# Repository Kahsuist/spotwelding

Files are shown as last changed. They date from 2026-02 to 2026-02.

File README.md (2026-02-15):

# Максимально бюджетный аппарат точечной сварки для 18650 и подобных





Полевые ключи от матринской платы по питанию процессора. OLED-дисплей 0.96". Bluepill на STM32 c алиэкспресс. 

**Архивный проект 2023 года** — аппарат точечной сварки двухимпульсный (разогрев + сварка) на базе STM32. Используется в комплекте с автомобильным аккумулятором, но подойдет любой высокотоковый 12в. Можно использовать конденсаторное питание, но я не тестировал, так как ставилась цель сотни непрерывных сварок подряд.

https://github.com/user-attachments/assets/1fbc5b3e-b446-4555-8be0-63c3d0c397dd

## Возможности

- Приваривает ленту с алиэкспресс 0.12*7мм к Li-ion аккумуляторам (18650 и др.)
- Автоматическая ручка с регулировкой прижима - гарантирует стабильное усилие на обоих электродах в момент сварки.
- Ручка автоматически подает сварочные импульсы в момент оптимального прижатия ОБОИХ электродов.
- Качество сварки без почернений, прожигов, непроваров (!!! необходимо настроить под свою ленту, так как часто не известно что у вас в руках!)
- OLED-дисплей отображает длительность двух импульсов и длительность паузы между ними и напряжение на аккумуляторе.
- Клавиатура позволяет настроить все три длительности.
- Возможности сохранить предустановки нет, при подключении к питанию берутся дефолтные значения из кода.
- Работает на STM32F103 (Blue Pill / Black Pill и т.п.)
- ВНИМАНИЕ!!! настройка длительностей более 10-15 миллисекунд приводит к выгоранию полевых ключей !!!

## Фото устройства

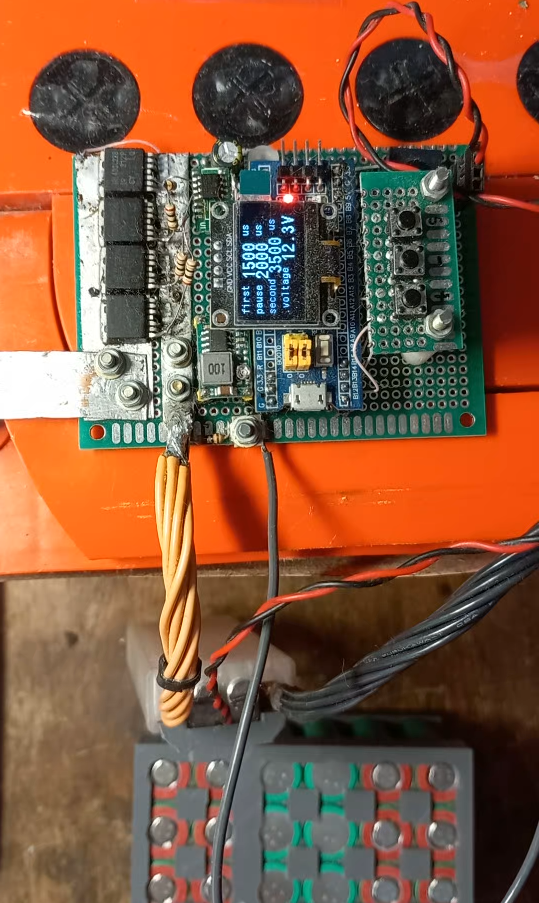
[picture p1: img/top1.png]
Собранное устройство сверху
  
*Собранное устройство (вид сверху)*

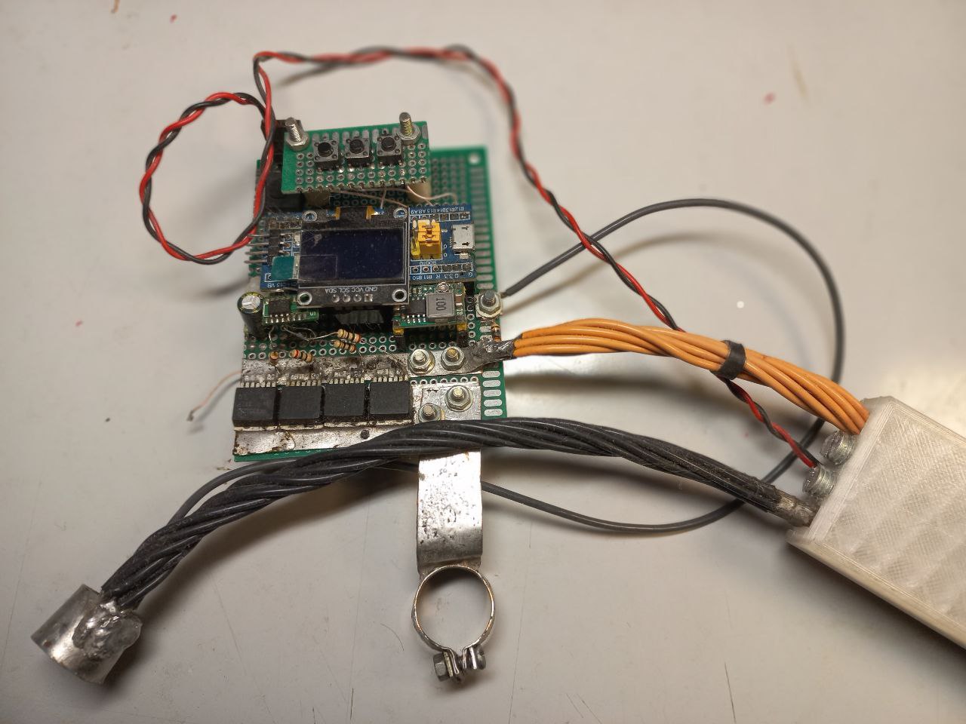
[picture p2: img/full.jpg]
Собранное устройство общий
  
*Собранное устройство (общий вид)*

## Фото автоматической сварочной ручки

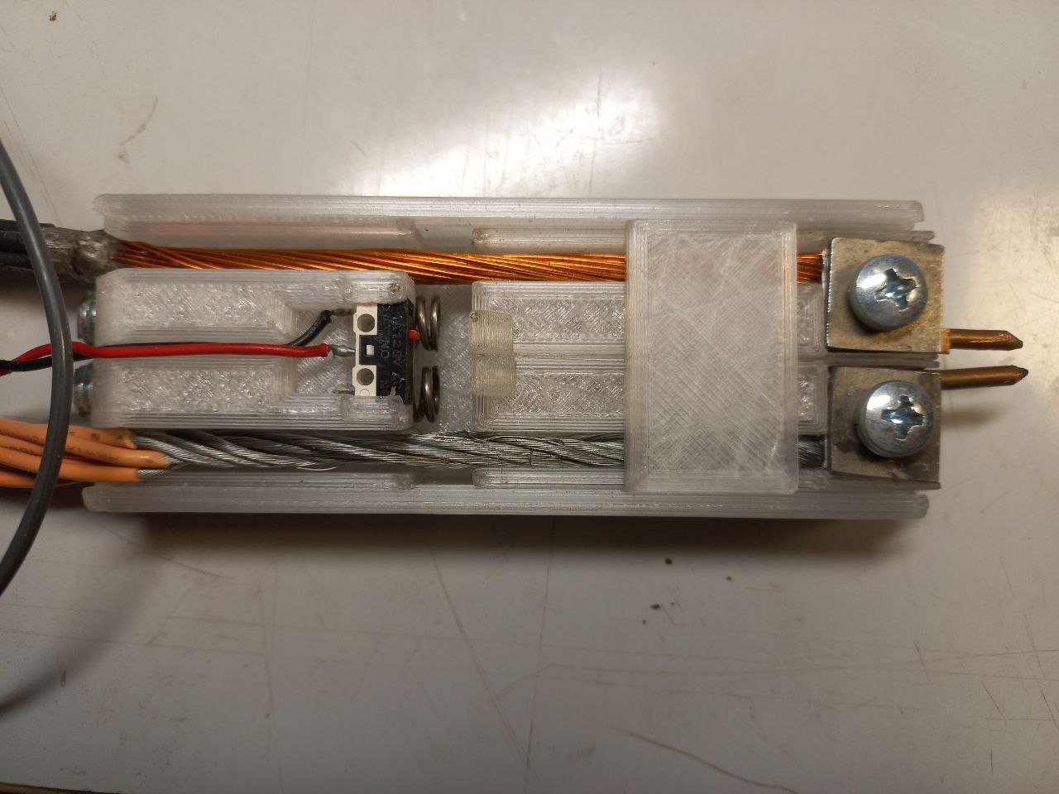
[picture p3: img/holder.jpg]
Сварочная ручка
  
*Сварочная ручка*

## Электрическая схема

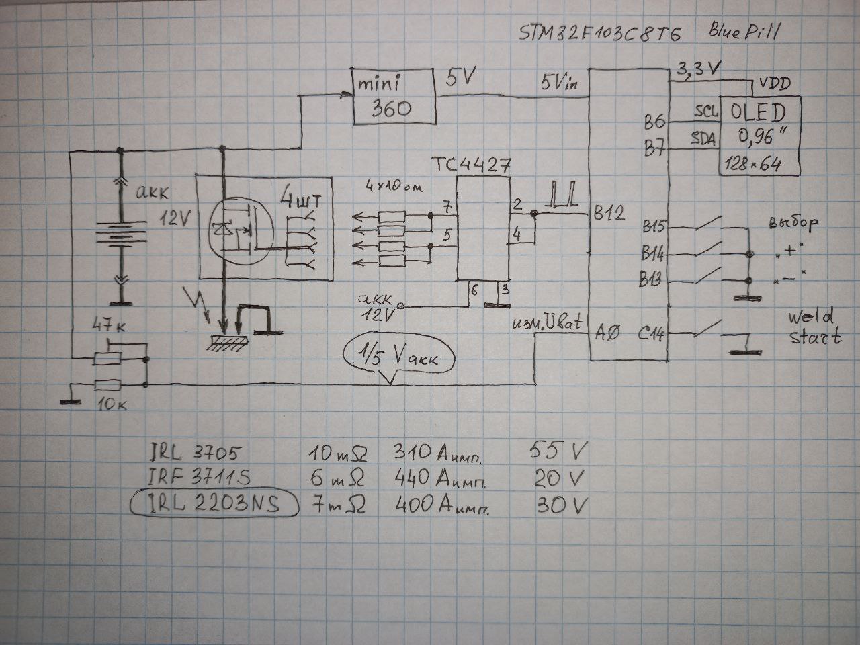
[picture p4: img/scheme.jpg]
Схема на бумаге
  
*Полная электрическая схема*

Подробные файлы схемы:  
- (в планах) ~~[KiCad проект → schematic.kicad_sch](hardware/schematics/)~~
- (в планах) ~~[Экспорт в PDF → schematic.pdf](hardware/schematics/schematic.pdf)~~

## Как открыть и собрать проект

1. Установи **STM32CubeIDE** (изначально создавался в 1.4, позже компилировался в версии 1.7)
2. File → Open Projects from File System... → укажи корень репозитория
3. Открой файл `*.ioc` в STM32CubeMX (если нужно изменить пины/настройки)
4. Project → Build All
5. Подключи ST-Link / USB → Run / Debug

**Прошивка без IDE** (опционально):  
Используй `*.hex` / `*.bin` из папки Release/Debug + STM32CubeProgrammer или dfu-util. (в репо не залиты, это сообщение оставлено для памяти)

## Как использовать

1. Подключи устройство к аккумулятору
2. При первых пробах подбери длительности по качеству сварки: провар должен быть 100% надежный, без прогаров, без почернений. !!! НЕ УВЛЕКАЙСЯ большими длительностями (max 10 миллисекунд) !!! 
3. ВАЖНО! - Перед использованием ленту необходимо подготовить - сделать продольные прорезы между точками сварки, на концах ножницами, в серединках - дримером (бормашинкой) с алмазным диском. БЕЗ прорезов качество становится неконтролируемым и требуются токи, не совместимые с дешевыми полевыми ключами !!! (я вообще использовал ключи, снятые с мертвых материнских плат по питанию процессора)
4. ВАЖНО обсепечить чистые поверхности, без мусора, между лентой и аккумулятором для обеспечения надежного контакта для прохождения сварочного тока.

## Зависимости / Требования

- STM32CubeIDE / STM32CubeMX
- STM32F103C8/R8 серия bluepill

## Disclaimer

Проект старый, не поддерживается.  
Это рабочий отлаженный прототип. Но возможен апгрейд проекта (например добавить запоминание настроек, настройка с телефона по блютуз, сбор статистики и др.) при обоюдовыгодном интересе.

Используй на свой страх и риск.  
Сообщения об ошибках / PR приветствуются!

## Лицензия

MIT License — см. файл [LICENSE](LICENSE)

## Контакты

Если хотите со мной связаться: телега @kahsuist

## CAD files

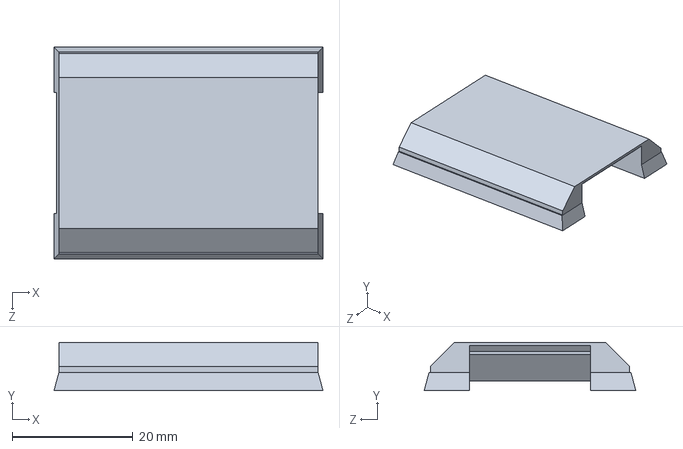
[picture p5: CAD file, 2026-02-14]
3Dmodels/крышка.SLDPRT
44.6 x 8.00 x 35.1 mm

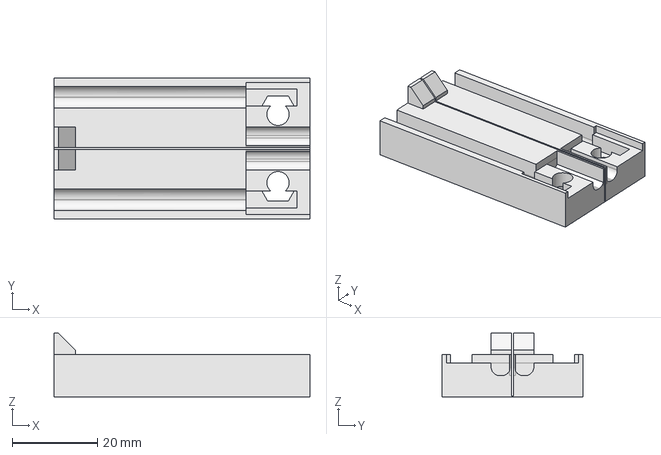
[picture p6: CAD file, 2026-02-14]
3Dmodels/base.FCStd
60.0 x 33.0 x 15.0 mm

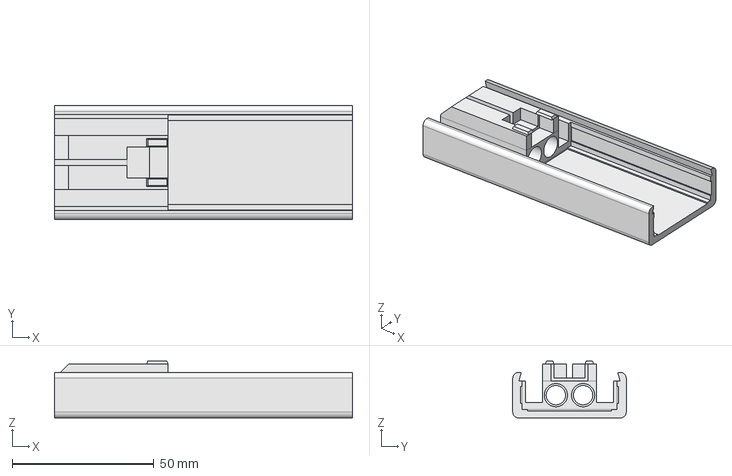
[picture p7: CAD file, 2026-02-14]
3Dmodels/shassi.FCStd
105.0 x 40.0 x 20.0 mm

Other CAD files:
3Dmodels/base.stl
3Dmodels/shassi.stl
3Dmodels/крышка.STL

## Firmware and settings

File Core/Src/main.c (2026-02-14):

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
/* Includes ------------------------------------------------------------------*/
#include "main.h"

/* USER CODE BEGIN Includes */
#include "ssd1306.h"
#include "fonts.h"
/* USER CODE END Includes */

/* USER CODE BEGIN PD */
#define DWT_CONTROL *(volatile unsigned long *)0xE0001000
#define SCB_DEMCR   *(volatile unsigned long *)0xE000EDFC
/* USER CODE END PD */

ADC_HandleTypeDef hadc1;

I2C_HandleTypeDef hi2c1;

TIM_HandleTypeDef htim2;

/* USER CODE BEGIN PV */
// кнопки
int8_t Select = 0;
int8_t position = 4;
int8_t value_up = 0;
int8_t value_down = 0;
int8_t letsWelding = 0;
uint32_t time_key_press = 0;// time_key_press = HAL_GetTick(); (HAL_GetTick() - time_key1_press) > 300
int8_t correction = 14; // поправка, причина в стартовой задержке в 14 микросекунд в delay_microseconds(), я не знаб почему

int voltage = 12;
char str[5];
int firstPulse = 400;
int pause = 3200;
int secondPulse = 1400;
/* USER CODE END PV */

void SystemClock_Config(void);
static void MX_GPIO_Init(void);
static void MX_I2C1_Init(void);
static void MX_ADC1_Init(void);
static void MX_TIM2_Init(void);
/* USER CODE BEGIN 0 */
void usDelay(uint16_t useconds)
{
  __HAL_TIM_SET_COUNTER(&htim2, 0);
  while(__HAL_TIM_GET_COUNTER(&htim2) < useconds);
}

void DWT_Init(void) // OK
{
    SCB_DEMCR |= CoreDebug_DEMCR_TRCENA_Msk; // разрешаем использовать счётчик
	DWT_CONTROL |= DWT_CTRL_CYCCNTENA_Msk;   // запускаем счётчик
}

void blinkLED(int count)
{
	for(int i=0; i<count; i++)
	{
		HAL_GPIO_WritePin(led13_GPIO_Port, led13_Pin, GPIO_PIN_RESET);
		HAL_Delay(100);
		HAL_GPIO_WritePin(led13_GPIO_Port, led13_Pin, GPIO_PIN_SET);
		HAL_Delay(100);
	}
	HAL_Delay(300);
}

void delay_microseconds(uint32_t usec)
{
    uint32_t us_count_tic =  usec * (SystemCoreClock / 1000000);
    DWT->CYCCNT = 0U; // обнуляем счётчик
    while(DWT->CYCCNT < us_count_tic); //{blinkLED(1);}
}

void test_uSecondDelayFunc(void)
{
	int i=0;
	  while(1)
	  {
		HAL_GPIO_TogglePin(WELD_OUT_GPIO_Port, WELD_OUT_Pin);
		//usDelay(40); // 10->100 uSec 40->370 uSec
		delay_microseconds(100); // 1->14uSec 10->24uSec 100->114uSec
		i+=1;
		if(i>100000) break;
	  }
}

void updateDelays(int inc)
{
	if(position==1) firstPulse = firstPulse + inc;
	if(position==2) pause = pause + inc;
	if(position==3) secondPulse = secondPulse + inc;
}

void keyboard(void)
{
	if(Select==0 && HAL_GPIO_ReadPin(GPIOB, BTN_SELECT_Pin)==GPIO_PIN_RESET)
	{
		time_key_press = HAL_GetTick();
		Select=1;
		if(position==4) position=1;
		else position++;
	}
	if(Select>0 && (HAL_GetTick() - time_key_press) > 300) Select=0;

	if(value_up==0 && HAL_GPIO_ReadPin(GPIOB, BTN_UP_Pin)==GPIO_PIN_RESET)
	{
		time_key_press = HAL_GetTick();
		value_up=1;
		updateDelays(100);
	}
	if(value_up>0 && (HAL_GetTick() - time_key_press) > 300) value_up=0;

	if(value_down==0 && HAL_GPIO_ReadPin(GPIOB, BTN_DOWN_Pin)==GPIO_PIN_RESET)
	{
		time_key_press = HAL_GetTick();
		value_down=1;
		updateDelays(-100);
	}
	if(value_down>0 && (HAL_GetTick() - time_key_press) > 300) value_down=0;

	if(letsWelding==0 && HAL_GPIO_ReadPin(LETS_WELD_GPIO_Port, LETS_WELD_Pin)==GPIO_PIN_RESET)
	{
		time_key_press = HAL_GetTick();
		letsWelding=1;
	}
	if(letsWelding>0 && (HAL_GetTick() - time_key_press) > 300) letsWelding=0;
}


/* USER CODE END 0 */

/**
  * @brief  The application entry point.
  * @retval int
  */
int main(void)
{
  /* MCU Configuration--------------------------------------------------------*/

  /* Reset of all peripherals, Initializes the Flash interface and the Systick. */
  HAL_Init();

  /* Configure the system clock */
  SystemClock_Config();

  /* Initialize all configured peripherals */
  MX_GPIO_Init();
  MX_I2C1_Init();
  MX_ADC1_Init();
  MX_TIM2_Init();
  /* USER CODE BEGIN 2 */
  SSD1306_Init();


  SSD1306_GotoXY(0,0);
  SSD1306_Puts ("Welding", &Font_11x18, 1);
  SSD1306_GotoXY(10,30);
  SSD1306_Puts ("Machine", &Font_11x18, 1);
  SSD1306_UpdateScreen();
  HAL_Delay(1500);
  blinkLED(1);

  //test_uSecondDelayFunc();



  SSD1306_Clear();

  HAL_TIM_Base_Start_IT(&htim2);

  /* USER CODE END 2 */

  /* Infinite loop */
  /* USER CODE BEGIN WHILE */
  while (1)
  {
	  keyboard();

	  HAL_ADC_Start(&hadc1);
	  HAL_ADC_PollForConversion(&hadc1, 100);
	  voltage = HAL_ADC_GetValue(&hadc1); // "T: %d.%d ->%d %d", temperatura/10, temperatura-(temperatura/10)*10,
	  int volH = voltage*0.0041;
	  int volL = (voltage*0.0041-volH)*10;
	  HAL_ADC_Stop(&hadc1);

	  if(Select==1 || value_up==1 || value_down==1) SSD1306_Clear();

	  SSD1306_GotoXY(1,0);
	  if(position==1) SSD1306_Puts (".", &Font_7x10, 1);
	  SSD1306_Puts ("first ", &Font_7x10, 1);
	  sprintf((char *)str, "%d", firstPulse);
      SSD1306_Puts (str, &Font_11x18, 1);
      SSD1306_Puts (" us", &Font_7x10, 1);

      SSD1306_GotoXY(1,15);
      if(position==2) SSD1306_Puts (".", &Font_7x10, 1);
      SSD1306_Puts ("pause ", &Font_7x10, 1);
      sprintf((char *)str, "%d", pause);
      SSD1306_Puts (str, &Font_11x18, 1);
      SSD1306_Puts (" us", &Font_7x10, 1);

      SSD1306_GotoXY(1,30);
      if(position==3) SSD1306_Puts (".", &Font_7x10, 1);
      SSD1306_Puts ("second ", &Font_7x10, 1);
      sprintf((char *)str, "%d", secondPulse);
      SSD1306_Puts (str, &Font_11x18, 1);
      SSD1306_Puts (" us", &Font_7x10, 1);

      SSD1306_GotoXY(1,45);
      if(position==4) SSD1306_Puts (".", &Font_7x10, 1);
      SSD1306_Puts ("voltage ", &Font_7x10, 1);
      sprintf((char *)str, "%d.%d", volH, volL);
      SSD1306_Puts (str, &Font_11x18, 1);
      SSD1306_Puts ("V ", &Font_11x18, 1);

	  SSD1306_UpdateScreen();
	    //HAL_Delay(200);

    /* USER CODE END WHILE */

    /* USER CODE BEGIN 3 */
	if(letsWelding==1)
	{
		blinkLED(1);
		HAL_GPIO_WritePin(WELD_OUT_GPIO_Port, WELD_OUT_Pin, GPIO_PIN_SET);
		blinkLED(2);
	    delay_microseconds(firstPulse-correction); // 	1->14uSec 10->24uSec 100->114uSec
	    blinkLED(3);
	    HAL_GPIO_WritePin(WELD_OUT_GPIO_Port, WELD_OUT_Pin, GPIO_PIN_RESET);
	    delay_microseconds(pause-correction);
	    HAL_GPIO_WritePin(WELD_OUT_GPIO_Port, WELD_OUT_Pin, GPIO_PIN_SET);
	    delay_microseconds(secondPulse-correction);
	    HAL_GPIO_WritePin(WELD_OUT_GPIO_Port, WELD_OUT_Pin, GPIO_PIN_RESET);
	    HAL_Delay(500);
	    letsWelding=0;
	}
	    //HAL_GPIO_WritePin(WELD_OUT_GPIO_Port, WELD_OUT_Pin, GPIO_PIN_SET); // WELD_OUT_GPIO_Port, WELD_OUT_Pin, GPIO_PIN_RESET

	    //HAL_TIM_PeriodElapsedCallback(&htim2);
	  //test_uSecondDelayFunc();
  }
  /* USER CODE END 3 */
}

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
/* USER CODE BEGIN 4 */
void HAL_TIM_PeriodElapsedCallback(TIM_HandleTypeDef *htim)
{
        if(htim->Instance == TIM2) //check if the interrupt comes from TIM1
        {
                //HAL_GPIO_TogglePin(led13_GPIO_Port, led13_Pin);
        }
}
/* USER CODE END 4 */
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


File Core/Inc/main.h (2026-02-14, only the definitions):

#define led13_Pin GPIO_PIN_13
#define led13_GPIO_Port GPIOC
#define LETS_WELD_Pin GPIO_PIN_14
#define LETS_WELD_GPIO_Port GPIOC
#define WELD_OUT_Pin GPIO_PIN_12
#define WELD_OUT_GPIO_Port GPIOB
#define BTN_DOWN_Pin GPIO_PIN_13
#define BTN_DOWN_GPIO_Port GPIOB
#define BTN_UP_Pin GPIO_PIN_14
#define BTN_UP_GPIO_Port GPIOB
#define BTN_SELECT_Pin GPIO_PIN_15
#define BTN_SELECT_GPIO_Port GPIOB

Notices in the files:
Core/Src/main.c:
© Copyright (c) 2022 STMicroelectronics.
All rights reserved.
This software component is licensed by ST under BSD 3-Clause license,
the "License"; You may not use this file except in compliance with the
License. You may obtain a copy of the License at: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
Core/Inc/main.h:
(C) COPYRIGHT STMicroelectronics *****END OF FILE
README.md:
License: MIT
